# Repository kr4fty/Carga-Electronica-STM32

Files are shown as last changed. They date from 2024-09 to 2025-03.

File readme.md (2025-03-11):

# CARGA ELECTRÓNICA FANTASMA

La carga electrónica fantasma es un dispositivo diseñado para simular una carga eléctrica, utilizado principalmente para pruebas y mediciones. 

Este proyecto está basado en un microcontrolador STM32F103, el cual controla la Vgs del MOSFET para regular la corriente.

**Estado del proyecto:** Funcional, pero aún en proceso de creación.

----------------- **BAJO SU RESPONSABILIDAD** ----------------------

### Video

[Demo](https://github.com/user-attachments/assets/e986f7fb-c2cd-4f63-a5ff-34d32783e475)

## Preparación Previa

Dado que cada transistor MOSFET presenta un voltaje umbral de puerta a fuente (Vgs Threshold) único, independientemente del fabricante o del código de identificación, es imperativo llevar a cabo mediciones específicas para determinar este voltaje umbral, así como la relación entre el ciclo de trabajo (Duty Cycle) y la corriente.

Para ello, se empleará el proyecto [Data Logger](https://github.com/kr4fty/DataLogger_STM32) con el fin de registrar estos parámetros. Posteriormente, los valores obtenidos se integrarán en este proyecto para facilitar el control adecuado de nuestra carga electrónica.

## Que incluye este repositorio?

Actualmente este repositorio cuenta con:
 - Diseño del hardware necesario para el proyecto
 - Codigo fuentes, tanto el de Control como la de adquicision de Datos
 - Archivo necesario para simular la placa BluePill, mediante PICSIMLAB

## Materiales

- **Placa:** BLUE PILL (STM32F103)
- **Encoder con botón**
- **Pantalla LCD:** Nokia 5110
- **Buzzer**
- **Sensor de temperatura:** LM35
- **Cooler Fan**
- **Transistor/s MOSFET:** IRFZ44
- **Sensor de corriente:** ACS712-05B

## Principio de Funcionamiento

El MOSFET opera en la zona de saturación (o zona lineal), lo que permite mantener una corriente constante independientemente de la tensión Vds de entrada. Esta característica es ventajosa para nuestra aplicación, ya que al variar la tensión Vgs podemos ajustar la corriente de salida de manera precisa.

La tensión Vds será controlada mediante el STM32F103 utilizando modulación por ancho de pulso (PWM) y un filtro pasa-bajos para obtener una señal de conversión digital a analógica (DAC) de 12 bits.

Debido a la inestabilidad de la potencia con respecto a la temperatura de los mosfset, el lazo de control sera realizado mediante un PID, el cual debera tener en cuenta el rango de temperaturas no solo para mantener la corriente constante, si no tambien para mantener a salvo al dispositivo.

#### Consideraciones importantes de los transistores Mosfet

- **Tensión de umbral (Vgs threshold):** Es el voltaje mínimo que debe aplicarse entre la puerta y la fuente para que el MOSFET comience a conducir corriente entre el drenador y la fuente.
- **Disipación de potencia:** Operar en la zona de saturación genera una significativa disipación de potencia en el MOSFET. Por lo tanto, es necesario implementar un sistema de disipación forzada para evitar el sobrecalentamiento.

#### Modos de Operacion
* Modo de **Corriente Constante**: Este es el modo predeterminado de operación, en el cual el dispositivo mantiene un nivel de corriente constante, determinado por el operador. Este modo es ideal para evaluar el comportamiento de una fuente o batería al operar bajo una corriente estable.
* Modo de **Potencia Constante**: En este modo, el dispositivo ajusta automáticamente la corriente para mantener la potencia consumida constante en la carga. Este enfoque es útil en situaciones donde es crítico mantener un nivel de potencia específico.
* Modo de **Tiempo**: Este modo permite al operador establecer un intervalo de tiempo durante el cual la carga permanecerá activa. Se pueden utilizar cualquiera de los modos anteriores en conjunto con este, según las necesidades de la aplicación.

## Modo de Funcionamiento

 * Al encender el equipo:
  El sistema muestra una pantalla con los siguientes parámetros:
    * **Tensión mínima (Vmin Limite):** 0.00 V (por defecto).
    * **Corriente de carga:** 1.00 A (por defecto).
    * **Modo de Operación:** "Corriente Constante" (por defecto).

 * Modificación de parámetros:
    * **Selección de parámetros:** Gira el encoder para resaltar el parámetro deseado (se invertirán los colores en el seleccionado).
    * **Edición de parámetros:** Realiza un giro rápido hacia la izquierda para entrar en modo edición. El parámetro comenzará a parpadear.
    * **Ajuste de valores:** Gira el encoder para incrementar o decrementar el valor.
    * **Confirmación:** Espera 2 segundos para salir del modo edición.

* Inicio del proceso:
    * **Inicio:** Haz un click corto en el botón para comenzar el proceso.
    * **Parada:** Un click corto detendrá el proceso.

* Modificación de parámetros estando el proceso en funcionamiento:
    - Puedes editar los parámetros de la misma manera que en el estado inicial de arranque (selección y edición).

* Menú:
    * **Acceso al menú:** Haz un doble click en el botón.

    * **Opciones del menú:**
        * Configurar
            * Backlight.
        * Modo de Trabajo
            * Corriente Cte.
            * Potencia Cte.
            * Resistencia Cte.
            * Tiempo Limite
            * Prueba de carga
            * Reset modo actual
        * Set Vmin Limite
        * Calibración
            * Calibrar
            * Ver parámetros
            * Borrar parámetros
        * Reiniciar MCU
        * Salir del Menú

## Hardware

El diseño del hardware se realizó utilizando KiCad, y se ha optimizado para facilitar la conexión de todos los componentes. A continuación, se detallan los aspectos clave del diseño:

### Consideraciones de Diseño

- **Disipación de Calor:** Asegúrate de que el MOSFET esté montado en un disipador de calor adecuado para evitar el sobrecalentamiento durante su operación.
- **Conexiones Seguras:** Verifica que todas las conexiones sean seguras y que no haya cortocircuitos, especialmente en la zona de alimentación.
- **Alimentación:** Utiliza una fuente de alimentación adecuada que pueda proporcionar la corriente necesaria para la carga que se va a simular.

### Imagen del PCB

Esquema del Hardware
---

Este documento proporciona una visión general del proyecto y su funcionamiento. Asegúrate de seguir las indicaciones de seguridad al trabajar con componentes electrónicos y realizar pruebas.

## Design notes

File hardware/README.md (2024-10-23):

# Hardware

Diseño realizado en KiCAD 8.0.4

## Diagrama electrónico

Diagrama

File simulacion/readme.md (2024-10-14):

# SIMULACIÓN

PICSIMLAB

### PASOS para realizar la simulación

1. Instalar [PICSIMLAB](https://github.com/lcgamboa/picsimlab)
2. Abre el archivo `Carga.pzw` con PICSIMLAB (`File->Load Workspace`); este se ejecutará automáticamente.
3. Si deseas cargar un archivo BIN, asegúrate de seleccionar el entorno **generic_qemu** dentro de `platformio.ini` y luego compilarlo:

**platformio.ini**
``` platformio.ini
[platformio]
;default_envs = nanoatmega328
;default_envs = wroom
;default_envs = generic_dfu
;default_envs = generic_hid_dapboot
;default_envs = generic_hid
;default_envs = generic_serial
;default_envs = generic_stlinkv2
default_envs = generic_qemu         ; <----- DESCOMENTAR!!!

...

[env:generic_qemu] ; Usando qemu, https://lcgamboa.github.io/picsimlab_docs/0.9.2/armgdbDebug.html#x50-490006.3.1
platform = ststm32
board = bluepill_f103c8_128k
board_build.mcu = stm32f103c8t6
;board_build.core = maple
framework = arduino

upload_protocol = custom
...
```

Por ultimo, vamos a importar el BIN generado (`firmware.bin`)

```
File -> Load Bin
```

Y nos dirigimos a la dirección:

```
.pio/build/generic_qemu/firmware.bin
```

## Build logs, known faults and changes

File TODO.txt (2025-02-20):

IMPLEMENTACIÓN DE UN DAC (BluePill no cuenta con DAC)
-----------------------------------------------------
    Generar una salida PWM + filtro pasa bajos. Tener en cuenta la frecuencia 
    del PWM y la frecuencia de corte del filtro para la tasa de bits máxima del
    PWM en nuestra placa BluePill. A su vez la salida este MCU tiene una salida
    lógica de 3.3V, por lo que el filtro deberá tener una ganancia, dependiendo
    de la Vgs Threshold del mosfet
    SOLUCIÓN IMPLEMENTADA:
                    Se utiliza un Filtro Activo tipo Bessel de 2do Orden con una 
                    ganancia de 1.51
            http://sim.okawa-denshi.jp/en/OPseikiLowkeisan.htm

Manejo de un LCD [ HECHO ]
-------------------------
    Se usara un lcd de un Nokia 3310

Control de el mosfet que activa el Cooler Fan, driving
-----------------------------------------------------
    Como la salida lógica del STM32 es 3.3V, tendría que cambiar este IRF540N 
    por un 2N7002, por ejemplo. Revisar cuanto consume el cooler!!!
    SOLUCIÓN IMPLEMENTADA:
            Se implementa un driver simple mediante un transistor NPN
            https://www.laboratoriogluon.com/controlar-mosfets-de-potencia-irfz44n-con-3-3v/

Sensores de Tensión de la Batería
---------------------------------
    Se utiliza un divisor resistivo

    SOLUCIÓN IMPLEMENTADA:
                            Para calcularla see toma el valor de la tensión a 
                            1V y luego para calcular la V se utiliza la 
                            relación:
                                        V = ADC_V_ACTUAL / ADC_1V

Sensor de corriente ASC712
--------------------------
    La tensión de salida (Vout) del ACS712-05B se puede calcular utilizando la
    siguiente fórmula:

        Vout = Vcc/2 + (Sensibilidad x Corriente)

    donde Vcc es la tensión de alimentación del sensor (que es de 5V en este caso),
    Sensibilidad es la sensibilidad del sensor (que es de 0,185 V/A para el ACS712-05B) y 
    Corriente es la corriente que se está midiendo.

    Si asumimos que la tensión de alimentación es de 5V, la fórmula se convierte en:

        Vout = 2,5V + (0,185V/A x Corriente)

    Para una corriente de 5A, la tensión de salida sería:

        Vout = 2,5V + (0,185V/A x 5A)
        Vout = 2,5V + 0,925V
        Vout = 3,425V

    SOLUCIÓN IMPLEMENTADA:
                            Se toma el valor de la corriente a 0A y luego como 
                            referencia, la de 1A. Luego para calcular la I se
                            utiliza la relación:

                            I = (ADC_I_ACTUAL-ADC_0A) / (ADC_1A-ADC_0A)

Sensor de Temperatura LM35
--------------------------
    Rango de salida: de 0 a 1.5V máximo, en la configuración básica (2 a 150ºC)
            NO haría falta un convertidor de niveles 3.3 a 5V
            http://www.ocfreaks.com/interfacing-lm35-sensor-lpc2148/

Interrupciones del PWM cuando se usa tone()
-------------------------------------------
    Al invocar la función tone() de Arduino y mientras se tiene activa otra 
    salida PWM, se observa que se produce una interrupción en la salida de 
    dicho pin.
    
    SOLUCIÓN:
            Se implemento una función tone() personalizada, utilizando el TIM2,
            canal 2, perteneciente al gpio PA1

Interfaz
--------
    Estando apagado(a la espera)
        Mostrar la corriente de Carga deseada
    
    Estando encendido
        * Mostrar de alguna manera (por presión larga del botón, por ejemplo), 
          la corriente de salida seleccionada
        * Posibilidad de modificar dicha corriente de salida

        SOLUCIÓN IMPLEMENTADA:
                                Al girar el Encoder, se modificara
                                automáticamente el nuevo Setpoint. No hace
                                falta presionar el botón. Por ahora :|

EEPROM
------
Guardar el ultimo valor de corriente utilizado. De este modo en la próxima 
encendida ya podemos recuperarlo fácilmente.

    Se utilizará la implementación de Arduino, EEPROM.h

Salida PWM múltiple para el control de dos mosfet
-------------------------------------------------
    La idea es poder extender el rango de corriente de salida, pero por la 
    utilización de dos MOSFET de modo que la corriente quede divida y por lo 
    tanto cada uno calentara menos

    SOLUCIÓN IMPLEMENTADA:
                            Se utiliza dutycyle fijo en el segundo MOSFET, a la
                            mitad del setpoint.
                            ampereSetpoint = dutyCycleToAmpere(dutyCycle);
                        Output2 = ampereToDutycycle(ampereSetpoint/2, MOSFET2);

Ver estado de la Tensión de Entrada
-----------------------------------
    Esto es para no arrancar el PID si todavía no se conecto la BATERÍA/FUENTE
    Si el PID se sigue calculando en ausencia de Tensión, cuando conectamos la
    batería, la carga consume el máximo ya que estuvo intentando subirla, 
    máximo PID.

Pulsación larga para reiniciar parámetros
-----------------------------------------
    Una pulsación larga me reinicia los contadores de Tiempo, Wh y mAh

Alarmas por caída en la fuente a testear
----------------------------------------
    Indicar si la fuente cae demasiado, por debajo de un 15% por ejemplo, en su
    tensión de salida. Esto para indicar la calidad y si cumple con los 
    parámetros de salida indicadas.

dutyCycle a Amperes
-------------------
    Cuando se setea el nuevo setpoint por medio del encoder, la conversion 
    debería ser en función del ACS712?????

    selecciono corriente -> convierto a ADC -> convierto a dutyCycle

Agregar Modos de funcionamiento
-------------------------------
    Por ejemplo:
                Corriente constante por un determinado Tiempo
                Watts constantes
                Medición de mAh de una batería
                Reacción frente a pulsos de corriente, para ver si cae la Vin

    En Modo Potencia constate, que debería hacer?:
        * Configurar el *encoder* para tener nuevo rango de limites
          Si considero que voy a medir un máximo de 100W y con una resolución
          de 0.1W, por ejemplo, entonces mis limites serian de 0 a 1000.
        * Modificar la variables de control dependiendo del tipo de MODO
          seleccionado.
          Ahora el Input seria la tensión y corriente (potencia) leídas en cada
          ciclo. A su vez el Setpoint sera la Potencia deseada. En tanto el 
          Output seguirá siendo dutyCycle ya que es el único parámetro que se 
          puede controlar para controlar la corriente.
          Tener en cuenta que en este caso variaran tanto la tensión como la
          la corriente al mismo tiempo(en el mejor de los casos solo variara 
          uno, dependiendo del tipo de fuente). Por lo que el Setpoint deberá 
          ajustarse continuamente ya que solo podemos controla la corriente.
        * Modo Inteligente (Prueba de carga)
          Con este modo se intentaría comprobar el valor de corriente máxima
          entregada por una fuente.
          En dicho modo se debería ir subiendo, desde 0 por ejemplo, la
          corriente hasta que veamos que la fuente cae por debajo de un 10/15% 
          de su valor nominal

Formas en que se muestra la Corriente [HECHO]
-------------------------------------
    Para corriente menor a 1A, 1000mA, se debería mostrar otra escala

        por ejemplo: en lugar de mostrar 0.15A se debería mostrar 150mA

Notificación cuando se conecta/desconecta la fuente/batería estando Menu activo
-------------------------------------------------------------------------------
    Resulta molesto la notificación de "No battery" cuando se ingresa a la
    configuración.
    En caso de ingresar al Menu, debería inhabilitarse las notificaciones hasta
    que se sale de dicho Menu.

        Solo voy a mostrar la notificación de Batería desconectada, cuando no
        este dentro del Menu

Limite inferior, V min, de descarga
-----------------------------------
    El limite inferior de descarga es para no dañar las baterías, ya que si
    bajan por debajo de 2.7V, por ejemplo, podrían dañarse.
    También si se quiere poner otro limite seguro de caída tensión, en fuentes
    o baterías.

        Al iniciar, girando el Encoder seleccionamos para setear la V min o la
        Corriente de Carga. Para configurar el parámetro deseado hacemos un
        click, corto, movemos el encoder para setear el valor y por ultimo
        hacemos otro click corto para volver a la selección de configuración.
        Una vez seteado los dos parámetros o solo el deseado, hacemos un click
        Largo para continuar y arrancar el proceso.

        En caso de NO querer modificar ninguno de los parámetros en el arranque,
        solo basta con hacer un Click Largo y ya podemos iniciar el proceso 
        normalmente.
        
        Si quisiéramos modificar la V min cuando el proceso ya esta en 
        funcionamiento, solo debemos entrar al Menu, con Doble click, y ahi
        vamos a  "Configurar" y seleccionamos "V mínimo" para modificarlo.

        Al iniciar, ya configurado los parámetros iniciales, o no, y estando el
        proceso apagado, se mostrara los limites configurados de Tensión y
        Corriente en colores invertidos.

Interfaz simplificada [NO IMPLEMENTADA]
---------------------
    La idea es hacerla lo mas simple posible, que para activar la Carga, la 
    idea es que la misma tenga la menor cantidad de pasos. Por ejemplo:

        Arranca y muestra la Corriente en negrita, signo de que ese parámetro
        se puede modificar. Caso contrario, girando hacia la derecha, me cambia
        hacia otro parámetro. Por ejemplo la secuencia:

            ...->Corriente->mAh->Wh->Tiempo->Tensión de corte->Corriente->.....
        
        Si giro hacia la izquierda, estando resaltado el parámetro que quisiera
        modificar, comienza a parpadear (cambiando Negro sobre blanco a Blanco 
        sobre Negro), se habilita para modificarlo.
        Luego si el parámetro esta en el valor deseado, solo con hacer un click
        corto ya quedaría seteado.

        Finalmente para arrancar el proceso hacemos un Click, suponiendo que 
        los parámetros ya están en los valores deseados.

        En caso de Iniciar y querer usar la configuración por default, solo 
        bastaría con hacer un Click para que se inicie.

        En caso de ya estar en funcionamiento el proceso y si se quisiera 
        modificar algún parámetro, solo bastaría con hacer un Doble Click para 
        ingresar al Menu y desde ahi modificar lo deseado.

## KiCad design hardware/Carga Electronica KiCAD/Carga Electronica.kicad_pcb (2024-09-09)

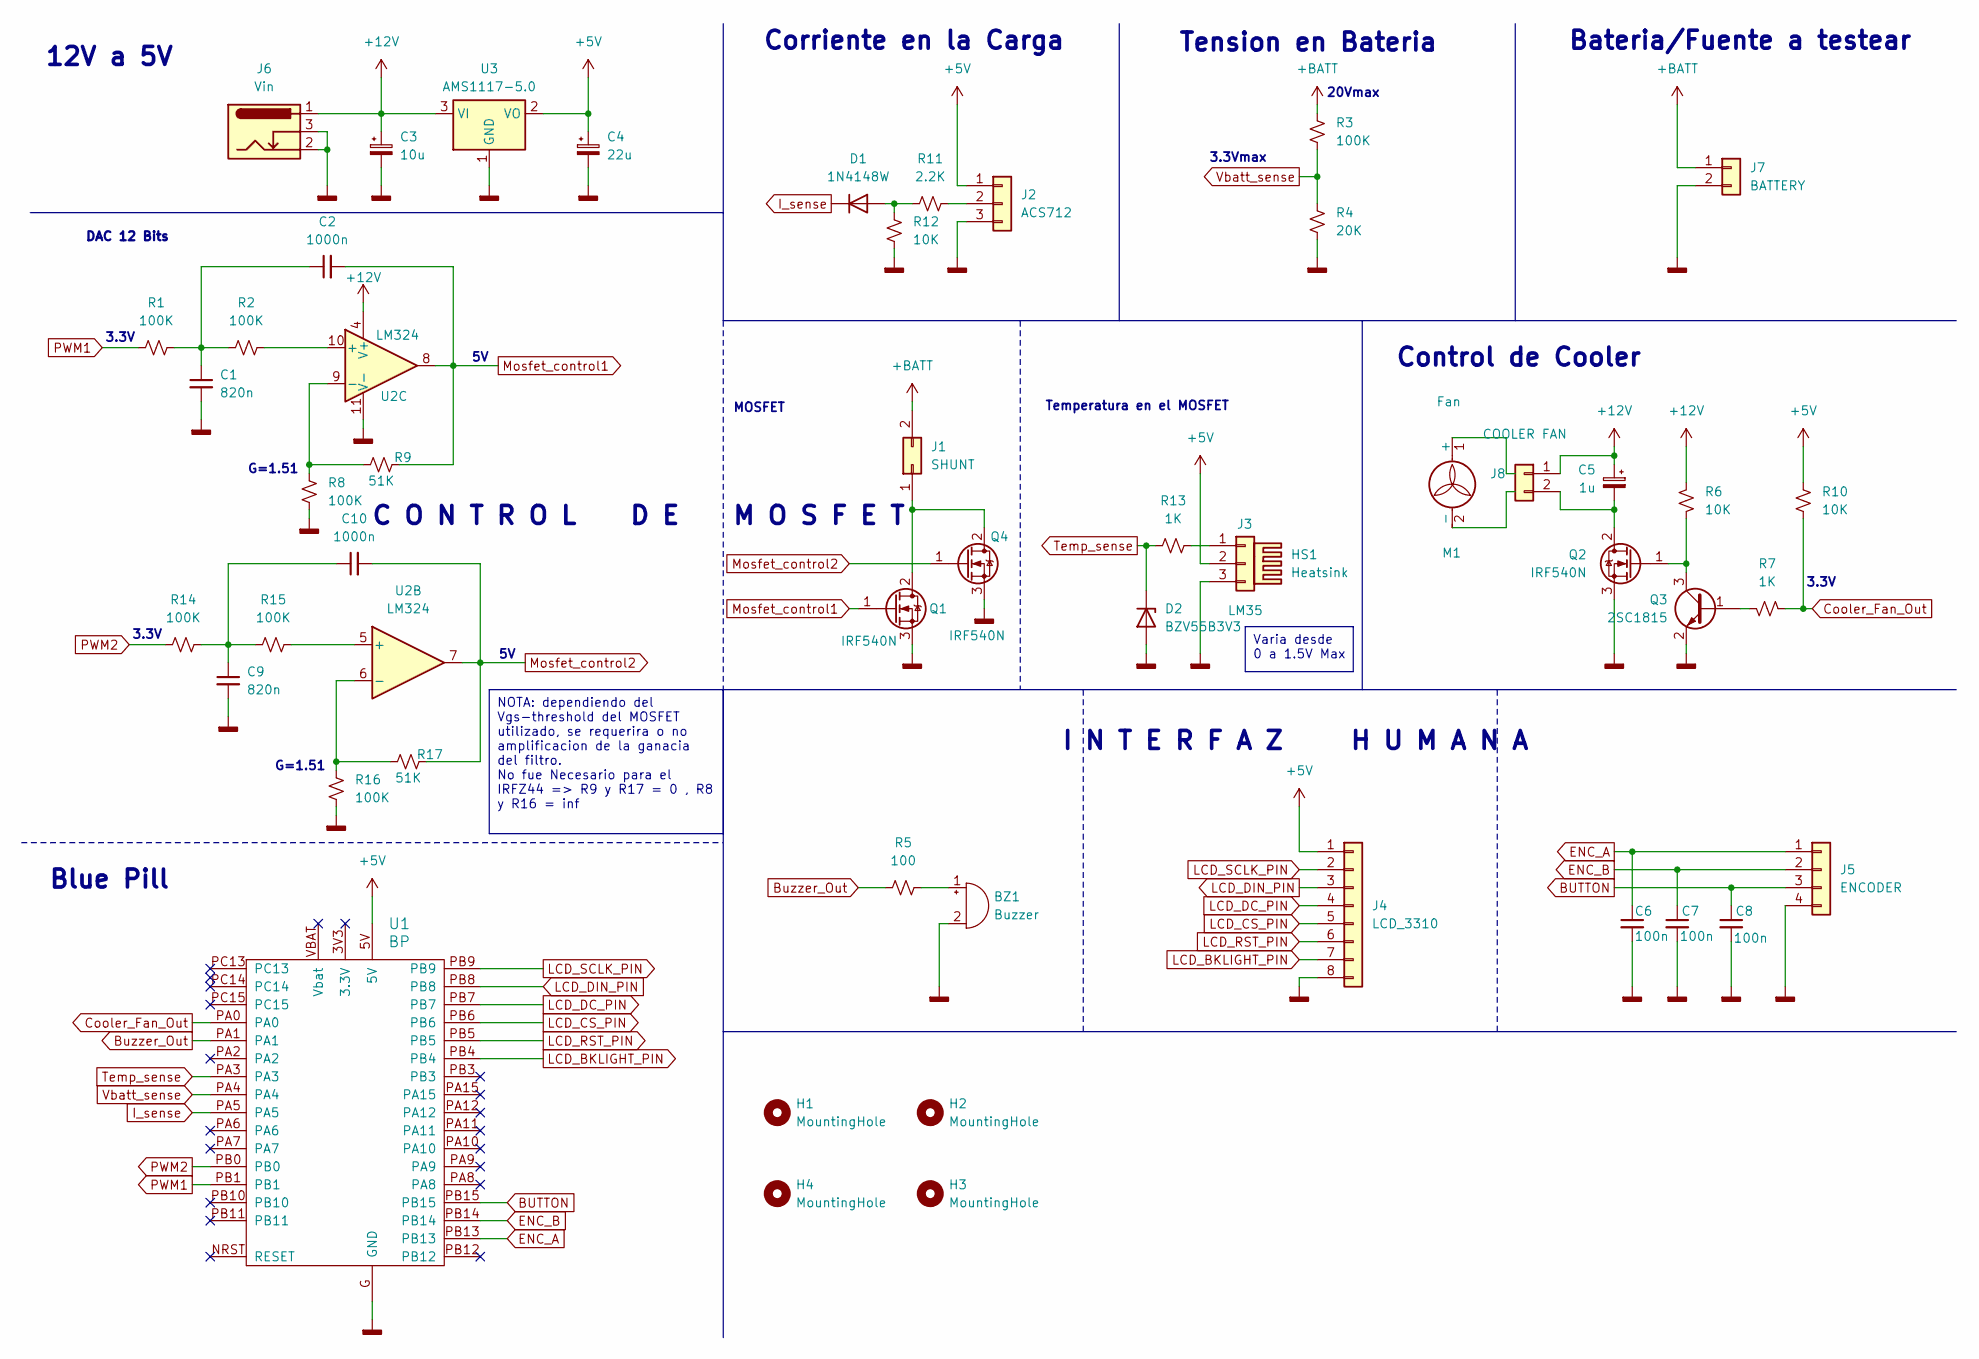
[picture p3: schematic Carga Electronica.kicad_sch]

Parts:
BZ1: Buzzer; Buzzer_TDK_PS1240P02BT_D12.2mm_H6.5mm
C1, C9: 820n; C_0805_2012Metric_Pad1.18x1.45mm_HandSolder
C2, C10: 1000n; C_0805_2012Metric_Pad1.18x1.45mm_HandSolder
C3: 10u; CP_Elec_6.3x5.2
C4: 22u; CP_Elec_6.3x5.2
C5: 1u; CP_Elec_6.3x5.2
C6, C7, C8: 100n; C_0805_2012Metric_Pad1.18x1.45mm_HandSolder
D1: 1N4148W; D_SOD-123
D2: BZV55B3V3; D_MiniMELF
H1, H2, H3, H4: MountingHole; MountingHole_2.5mm
HS1: Heatsink
J1: SHUNT; Molex_KK-396_5273-02A_1x02_P3.96mm_Vertical
J2: ACS712; Molex_KK-254_AE-6410-03A_1x03_P2.54mm_Vertical
J3: LM35; Molex_KK-254_AE-6410-03A_1x03_P2.54mm_Vertical
J4: LCD_3310; Molex_KK-254_AE-6410-08A_1x08_P2.54mm_Vertical
J5: ENCODER; Molex_KK-254_AE-6410-04A_1x04_P2.54mm_Vertical
J6: Vin; BarrelJack_Horizontal
J7: BATTERY; Molex_KK-396_5273-02A_1x02_P3.96mm_Vertical
J8: COOLER FAN; Molex_KK-396_5273-02A_1x02_P3.96mm_Vertical
M1: Fan; Molex_KK-254_AE-6410-02A_1x02_P2.54mm_Vertical
Q1, Q4: IRF540N; Molex_KK-396_5273-03A_1x03_P3.96mm_Vertical
Q2: IRF540N; TO-220-3_Vertical
Q3: 2SC1815; SOT-23
R1, R2, R8, R14, R15: 100K; R_0805_2012Metric_Pad1.20x1.40mm_HandSolder
R3, R16: 100K; R_1206_3216Metric_Pad1.30x1.75mm_HandSolder
R4: 20K; R_1206_3216Metric_Pad1.30x1.75mm_HandSolder
R5: 100; R_1206_3216Metric_Pad1.30x1.75mm_HandSolder
R6, R10: 10K; R_1206_3216Metric_Pad1.30x1.75mm_HandSolder
R7: 1K; R_1206_3216Metric_Pad1.30x1.75mm_HandSolder
R9, R17: 51K; R_0805_2012Metric_Pad1.20x1.40mm_HandSolder
R11: 2.2K; R_0805_2012Metric_Pad1.20x1.40mm_HandSolder
R12: 10K; R_0805_2012Metric_Pad1.20x1.40mm_HandSolder
R13: 1K; R_0805_2012Metric_Pad1.20x1.40mm_HandSolder
U1: BP; blue_pill_no_flashing_port
U2: LM324; SOIC-14_3.9x8.7mm_P1.27mm
U3: AMS1117-5.0; SOT-223-3_TabPin2

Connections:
+5V: C4.1, J2.1, J3.2, J4.1, R10.1, U1.5V, U3.2 (VO)
+12V: C3.1, C5.1, J6.1, J8.1, R6.1, U2.4 (V+), U3.3 (VI)
+BATT: J1.2, J7.1, R3.1
BUTTON: C8.1, J5.3, U1.PB15
Buzzer_Out: R5.1, U1.PA1
Cooler_Fan_Out: R7.2, R10.2, U1.PA0
ENC_A: C6.1, J5.1, U1.PB13
ENC_B: C7.1, J5.2, U1.PB14
GNDD: BZ1.2 (-), C1.2, C3.2, C4.2, C6.2, C7.2, C8.2, C9.2, D2.2 (A), J2.3, J3.3, J4.8, J5.4, J6.2, J6.3, J7.2, Q1.3 (S), Q2.3 (S), Q3.2 (E), Q4.3 (S), R4.2, R8.2, R12.2, R16.2, U1.G (GND), U2.11 (V-), U3.1 (GND)
I_sense: D1.1 (K), U1.PA5
LCD_BKLIGHT_PIN: J4.7, U1.PB4
LCD_CS_PIN: J4.5, U1.PB6
LCD_DC_PIN: J4.4, U1.PB7
LCD_DIN_PIN: J4.3, U1.PB8
LCD_RST_PIN: J4.6, U1.PB5
LCD_SCLK_PIN: J4.2, U1.PB9
Mosfet_control1: C2.2, Q1.1 (G), R9.2, U2.8
Mosfet_control2: C10.2, Q4.1 (G), R17.2, U2.7
unnamed: BZ1.1 (+), R5.2
unnamed: C1.1, C2.1, R1.2, R2.1
unnamed: C9.1, C10.1, R14.2, R15.1
unnamed: D1.2 (A), R11.1, R12.1
unnamed: J1.1, Q1.2 (D), Q4.2 (D)
unnamed: J2.2, R11.2
unnamed: J3.1, R13.2
unnamed: C5.2, J8.2, Q2.2 (D)
unnamed: Q2.1 (G), Q3.3 (C), R6.2
unnamed: Q3.1 (B), R7.1
unnamed: R15.2, U2.5 (+)
unnamed: R16.1, R17.1, U2.6 (-)
unnamed: R2.2, U2.10 (+)
unnamed: R8.1, R9.1, U2.9 (-)
PWM1: R1.1, U1.PB1
PWM2: R14.1, U1.PB0
Temp_sense: D2.1 (K), R13.1, U1.PA3
Vbatt_sense: R3.2, R4.1, U1.PA4

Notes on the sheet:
NOTA: dependiendo del Vgs-threshold del MOSFET utilizado, se requerira o no amplificacion de la ganacia del filtro. No fue Necesario para el IRFZ44 => R9 y R17 = 0 , R8 y R16 = inf
Varia desde 0 a 1.5V Max
C O N T R O L D E M O S F E T
Corriente en la Carga
G=1.51
3.3V
MOSFET
Control de Cooler
DAC 12 Bits
Temperatura en el MOSFET
3.3Vmax
Tension en Bateria
Blue Pill
I N T E R F A Z H U M A N A
12V a 5V
20Vmax
Bateria/Fuente a testear

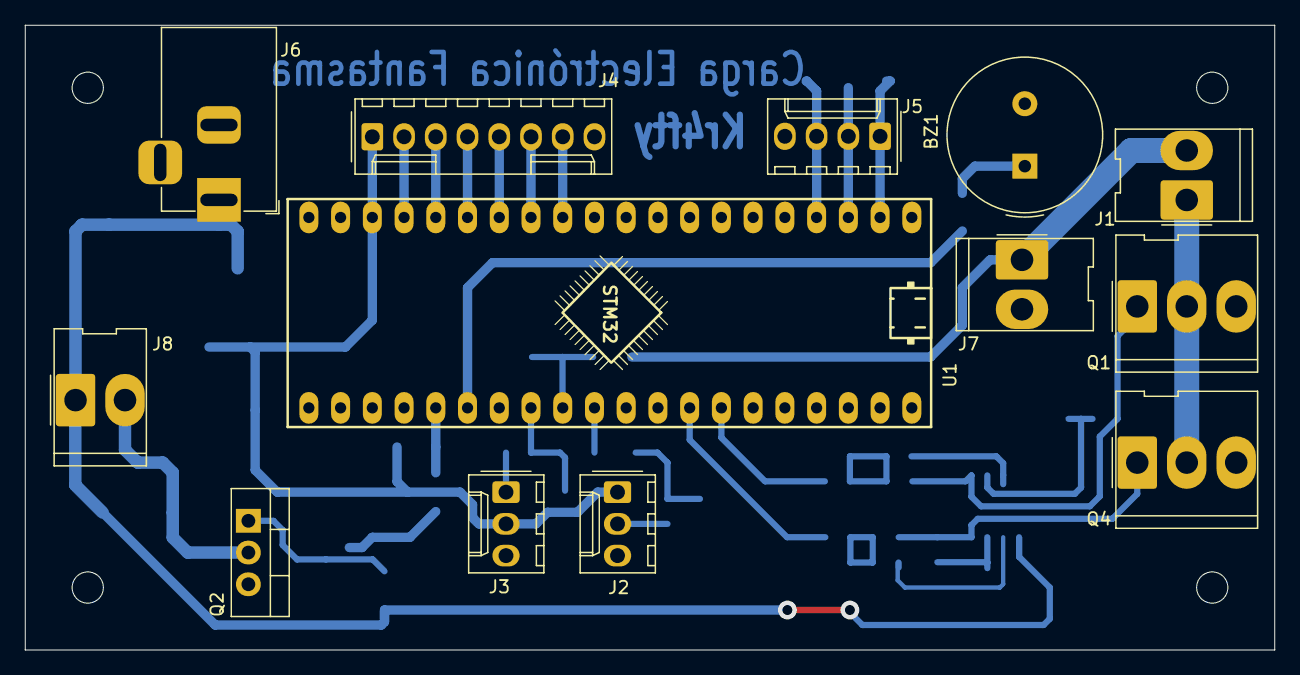
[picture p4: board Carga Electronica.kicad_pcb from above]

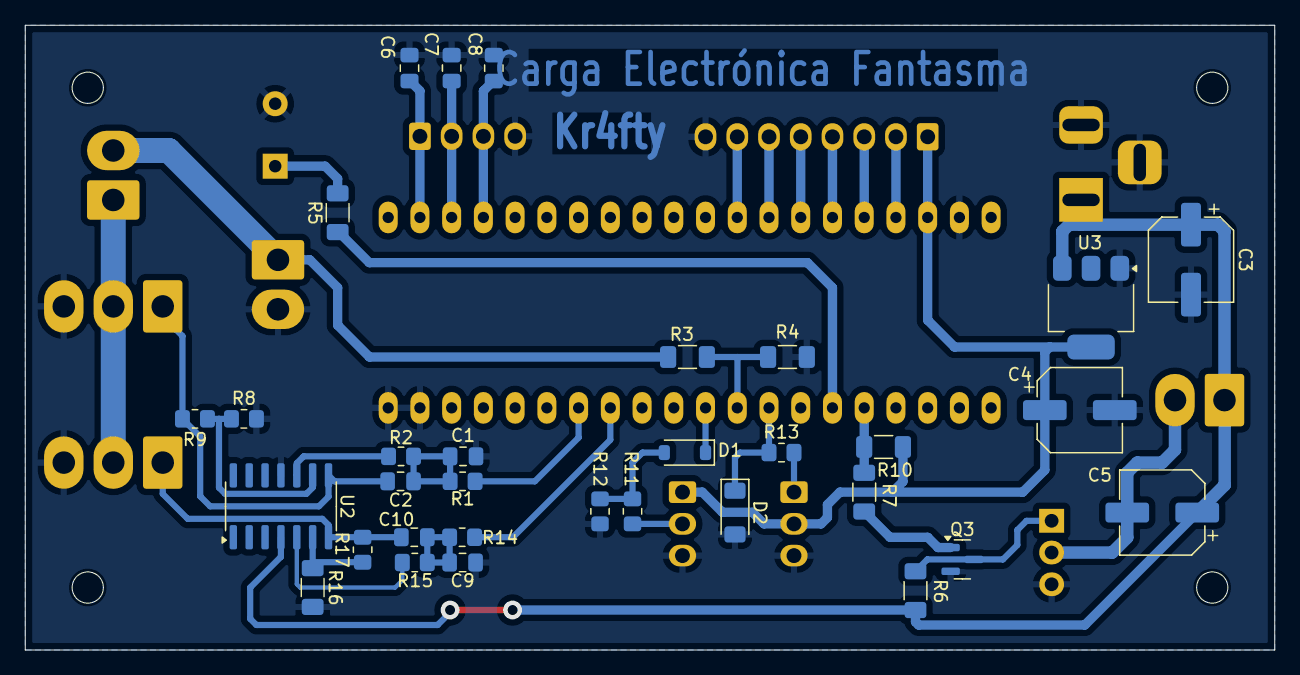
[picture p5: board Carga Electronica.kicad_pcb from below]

Board: 2 copper layers, 100.0 x 50.0 mm, 49 parts (32 on the bottom side), 36 nets.

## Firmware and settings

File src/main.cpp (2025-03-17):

#include <Arduino.h>
#include <PID_v1.h>
#include "config.h"
#include "encoder.h"
#include "display.h"
#include "pwm.h"
#include "sound.h"
#include "tclock.h"
#include "constantes.h"
#include "coolerfan.h"
#include "conversion.h"
#include "notifications.h"
#include "myMenu.h"
#include "calibrate.h"
#include "modes.h"
#include "control.h"

long encoderValue = 0;// Valor leído desde el encoder
float ampereSetpoint;// Contiene el valor del Setpoint expresado en Amperes
float powerSetpoint;// Contiene el valor de Setpoint expresado en Watts
float resistanceSetpoint; // Contiene el valor del Setpoint expresado en Ohmios
float vLimit=0;     // Valor de la tensión mínima de corte
double vBattRawOld; // Valor de lectura anterior del pin ADC que mide V
double iBattRawOld; // Valor de lectura anterior del pin ADC que mide I
double iAdcOffset;  // Lectura del ADC medida en vació (0 A)
double AdcRaw_1A;   // Lectura del ADC midiendo 1A
double Adc1aDiff;   // Contiene la diferencia en valores de ADC, entre 1A y 0A
float iIn, vIn, vInOld, wIn, totalmAh, totalWh; // Valores actuales de la V, I y Wh
uint8_t key; // 0: no click, 1: corta, 2: larga, 3: doble pulsación

double Setpoint, Input, Output; // Parámetro PID
//Specify the links and initial tuning parameters
PID myPID(&Input, &Output, &Setpoint, KP_AGG, KI_AGG, KD_AGG, DIRECT);
unsigned long windowStartTime;

#ifdef DEBUG
unsigned long nextTime, startTime, actualTime;
#define WINDOW_CAPTURE  40
#define WINDOW_10SEG 10000
#endif

void setup() {
    #ifdef DEBUG
    Serial.begin(115200);
    delay(5000);
    Serial.println("Iniciando");
    #endif
    pinMode(LED, OUTPUT);
    digitalWrite(LED, HIGH);
    
    lcd_init();
    encoder_init();
    pwm_init();
    coolerFan_init();
    tone_init();

    myPID.SetOutputLimits(ADC_VGS_THRESHOLE, 4095);
    myPID.SetSampleTime(PID_WINDOW_SIZE);  //sets the period, in Millisecond
    myPID.SetMode(AUTOMATIC); // Encendemos el PID

    // Lectura inicial de los sensores
    vBattRawOld = analogRead(VBATT_SENSE_PIN);
    iBattRawOld = analogRead(IBATT_SENSE_PIN);

    // Entrando a modo Calibración. Medimos una corriente de 1A para luego aplicar relación
    if(isButtonDown())
    {
        calibration_calibrate();
        if(!iAdcOffset || !AdcRaw_1A){
            calibration_resetParameters();
        }
    }
    else{
        // Recupero los parámetros de calibración de la Corriente desde la EEPROM
        calibration_readParameters();
    }

    vLimit = V_0V;              // 0 Volt
    controlMode; // Por default esta en C_CONST_MODE
    
    ampereSetpoint = C_1A;      // 1 Ampere
    powerSetpoint = P_1W;       // 1 Watt
    resistanceSetpoint = R_10R; // 10 Ohm

    //lcd_printBaseFrame(controlMode);
    lcd_printSelectBaseFrame();

    windowStartTime = millis();

    encoder_setBasicParameters(0, 299, true, 1, 2); // Configuro para selección de parámetro a modificar

    lcd_printSelectedParam(1, controlMode, COLOR_WB); // resalto
            
    encoderValue = encoder.readEncoder();

    Setpoint = 0;

    // Inicio Proceso de control
    tone(BUZZER_PIN, 2600, 250);
}

bool isPowerOn = false; // TRUE: en funcionamiento
long encoderValueChanged; // True: el valor del encoder cambio
int8_t encoderDirection;
double vRaw; // Valor crudo de la tensión de entrada, sin aplicar filtro, para detectar mas rápidamente la desconexión de la batería
double vBattRaw, iBattRaw; // Valores Leidos en los ADC
bool batteryConnected=true;  // True si se detecto tensión de sensado de batería
bool wasVUpdated=true, wasIUpdated=true, wasXhUpdated=true, wasTempUpdated=true; //True: Si los valores cambiaron, para re imprimir
bool wasCtrlModeUpdated=true;
uint16_t mosfetTempRaw, oldMosfetTempRaw;
float mosfetTemp; 
long timeToUpdateDisplay=millis()+DISPLAY_UPDATE_WINDOW;
uint8_t notificationPriority; // Contiene la prioridad de notificaciones
uint16_t time_mseg; // Tiempo en mili segundos
bool forceRePrint; // Para volver a imprimir toda la pantalla
bool isItOverheating=false;
bool isPrintTime=true;
bool isTheSetpointUpdated; // Para tener prioridad al mostrar nuevo setpoint
bool printTinySetpoint=true;
unsigned long timeToPrintNewSetpoint, windowNewSetpoint=2000;
double Output2; // Contiene el duty del segundo MOSFET. Varia con el setpoint
uint8_t oldControlMode; // Contiene el estado anterior del modo de control
long oldEncoderValue; // Para restaurar el valor del encoder al salir del menú
unsigned long timeLoadTestStart;
float vInNominal, vMaxForImax, iMax;
uint8_t paramNumber=1, oldParamNumber=0; // Parámetro seleccionado actual y anterior
long eventStartTime, eventEndTime; // Registran el tiempo de inicio y final del evento
long pulseCount; // Contador de ticks en cada evento (giro del encoder)
bool newValue; // True: si hubo un cambio, admitido, en el encoder
bool modifyParameter; // True: se entro en modo edición del parámetro seleccionado
bool actualColor; // Color actual del parámetro
bool firstTime=true; // True: para ejecutar acciones solo en el arranque
uint8_t colorCount; // Contador para indicar el cambio del color, modo edición

void loop() {
    /***************************************************************************/
    /*                    MEDICIÓN DE TENSIÓN Y CORRIENTE                      */
    /***************************************************************************/
    vRaw = analogRead(VBATT_SENSE_PIN);
    // Filtro de Wiener, Adaptativo
    vBattRaw = vBattRawOld + MU * (vRaw - vBattRawOld);  
    // Calculo de vIn
    vIn = 0.01935*vBattRaw + 0.25; // Función obtenida por regresión lineal

    if(vBattRaw != vBattRawOld){// si cambio V entonces actualizo valor en el LCD
        wasVUpdated = true;
        vBattRawOld = vBattRaw;
    }
    
    iBattRaw = (double)analogRead(IBATT_SENSE_PIN);
    // Filtro de Wiener, Adaptativo
    iBattRaw = iBattRawOld + MU * (iBattRaw - iBattRawOld);
    // Calculo iIn
    iIn = (iBattRaw - iAdcOffset) / Adc1aDiff;

    if(iBattRaw != iBattRawOld){ // si cambio I entonces actualizo valor en el LCD
        if(isPowerOn){
            wasIUpdated = true;
        }
        else{
            iAdcOffset = iBattRaw; // Corriente medida, valores de ADC, a 0A

            // Guardo la tensión nominal en vació
            vInNominal = vIn;
        }
        iBattRawOld = iBattRaw;
    }

    // Calculo wIn
    wIn = vIn * iIn;

    // Si vario la Vin entonces recalculo el setpoint para el modo P_CONST_MODE
    if(controlMode==P_CONST_MODE || controlMode==R_CONST_MODE){
        if(vIn != vInOld && isPowerOn){
            // Actualizo valores
            switch (controlMode)
            {
                case P_CONST_MODE:
                    ampereSetpoint =  powerSetpoint/vIn; // Cálculo de la corriente necesaria
                    break;
                case R_CONST_MODE:
                    ampereSetpoint = vIn/resistanceSetpoint; // Cálculo de la corriente necesaria
                break;
                default:
                    break;
            }

            Output2 = ampereToDutycycle(ampereSetpoint*.5, MOSFET2);
            
            Setpoint = ampereToAdc(ampereSetpoint);
            vInOld = vIn;
        }
    }
    // FIN Mediciones

    /***************************************************************************/
    /*                 ¿SE CONECTO LA FUENTE A LA ENTRADA?                     */
    /***************************************************************************/
    // Batería/Fuente conectada y funcionando? Detección persistente
    if(vRaw > VBATT_MIN){
        // Batería conectada
        if(!batteryConnected){
            // Solo se muestra si no se esta el Menu de configuración activo
            if(!showMenu && isPowerOn){
                // Solo mostramos una vez el mensaje
                notificationPriority = 3;
                time_mseg = 500;
                notification_add("BATT CONNECTED", notificationPriority, time_mseg, COLOR_BW);

                batteryConnected = true;
            }
        }
    }
    else{ // NO SE DETECTO TENSIÓN DE ENTRADA!!!
        if(batteryConnected){
            // Solo se muestra si no se esta el Menu de configuración activo
            if(!showMenu && isPowerOn){
                // Se muestra solo una vez y queda fijo hasta que no se cambie el estado
                notificationPriority = 3;
                notification_add("  NO BATTERY  ", notificationPriority, NO_TIME_LIMIT, COLOR_WB);

                // Emito un Sonido de alerta
                tone(BUZZER_PIN, 2000, 50);
                delay(50);
                tone(BUZZER_PIN, 2000, 50);
                delay(50);
                tone(BUZZER_PIN, 2000, 50);

                batteryConnected = false;
            }
            if(isPowerOn){
                control_stopOutputsAndReset();
                //myPID.SetMode(MANUAL);  // Apagamos el PID
            }
        }
    }
    // FIN DETECCIÓN DE TENSIÓN DE ENTRADA

    /******************************* Encoder *********************************/
    encoderValueChanged = encoder.encoderChanged();
    encoderDirection = encoder.getDirection();
    
    if(encoderValueChanged){        
        if(showMenu || modifyParameter){
            encoderValue = encoder.readEncoder();
            
            eventEndTime = millis();
            newValue = true;
        }
        else{
            if(!eventStartTime){
                eventStartTime = millis();
                pulseCount = 0;
            }
            
            pulseCount += encoderDirection;
            eventEndTime = millis();
        }
    }
    if(eventStartTime && !modifyParameter && (millis()-eventEndTime)>40){
        // Estando apagado, se produjo un evento y ya termino
        eventStartTime = 0;
        newValue = true; // Evento finalizado, hay nuevo valor
    }
    if(eventStartTime && modifyParameter && (millis()-eventEndTime)>2000){
        // Se termino el tiempo de espera para la edición del parámetro
        eventStartTime = 0;
        modifyParameter = false; // Ya no estoy en modo edición

        forceRePrint = true; // Fuerzo re imprimir la pantalla

        // Emito un Sonido de alerta
        tone(BUZZER_PIN, 7000, 20);
        delay(75);
        tone(BUZZER_PIN, 7000, 80);

        // Recupero configuración previa del contador del encoder
        if(firstTime){
            encoder_setBasicParameters(0, 299, true, paramNumber, 2);
        }
        else{
            encoder_setBasicParameters(0, 199, true, 1, 2);
        }
    }
    //

    /********************* Selección de Parámetro a modificar ****************/
    if(newValue && !showMenu && !modifyParameter){
        newValue = false;
        // Modificación del parámetro seleccionado
        if(abs(pulseCount)>2){ // Entrando a modo EDICIÓN
            if(encoderDirection<0){
                // Emito un Sonido de alerta
                tone(BUZZER_PIN, 2500, 50);
                tone(BUZZER_PIN, 0, 50);
                tone(BUZZER_PIN, 2500, 50);

                modifyParameter = true; // Modo edición activado

                // Re configurar los parámetros del encoder de acuerdo al modo actual de funcionamiento
                switch (paramNumber)
                {
                    case 0: // Modificación de Vlimit
                        encoder_setBasicParameters(0, 2000, false, vLimit*100, 150);
                        break;
                    
                    case 1: // Modificación de C, W o R
                        switch (controlMode){
                            case C_CONST_MODE:
                                encoder_setBasicParameters(0, 1000, false, ampereSetpoint*100, 100);
                                break;
                            case P_CONST_MODE:
                                encoder_setBasicParameters(0, 1000, false, powerSetpoint*10, 100);
                                break;
                            case R_CONST_MODE:
                                encoder_setBasicParameters(0, 1000, false, resistanceSetpoint*10, 100);
                                break;
                            default:
                                break;
                        }
                        break;
                    case 2: // Modo de operación
                        encoder_setBasicParameters(1, 3, true, 0, 0);
                        wasCtrlModeUpdated = true;
                        break;
                    case 3:
                        break;
                    case 4:
                        break;
                    default:
                        break;
                }
                // Como contiene un valor viejo entonces los actualizo
                encoderValue = encoder.readEncoder(); 

                // limpio 
                lcd_printSelectedParam(paramNumber, controlMode); // limpio

                eventStartTime = millis();
                eventEndTime = millis();
            }
            // 
            if(modifyParameter){
                if(isPowerOn){
                    // Si esta encendido el proceso entonces fuerzo a mostrar 
                    // la ventana del setpoint grande la primera vez
                    newValue = true;
                }
            }
        }
        else{ // Entrando en modo SELECCIÓN
            oldParamNumber = paramNumber;
            if(firstTime){
                paramNumber = encoder.readEncoder()%3;
            }
            else{
                paramNumber = encoder.readEncoder()%2;
            }

            lcd_printSelectedParam(oldParamNumber, controlMode); // limpio selección anterior
            lcd_printSelectedParam(paramNumber, controlMode, COLOR_WB); // resalto el actual

            tone(BUZZER_PIN, 600, 10);
        }
    }
    //

    /******************************** Menú ***********************************/
    if(showMenu && encoderValueChanged){
        // Resalto el nuevo Item seleccionado mediante el encoder
        menu.highlightMenuItem(encoderValue);
    }
    //

    /*************************************************************************/
    /*                      MODIFICACIÓN DE PARÁMETROS                       */
    /*************************************************************************/
    if(!isLoadTestRunning){ // No se selecciono la Prueba de Carga
        if(newValue){
            newValue = false;
            if (!showMenu){
                switch (paramNumber)
                {
                    case 0: // Limite de Tensión
                        vLimit = encoderValue/100.0;

                        if(isPowerOn){
                            lcd_printNewSetpoint(vLimit, V_LIMIT);
                            isTheSetpointUpdated = true;
                        }
                        else{
                            printTinySetpoint = true;
                        }
                        break;
                    case 1: // Limite principal 
                        // Calculo el Setpoint necesario en valores de Ampere normalizados
                        ampereSetpoint = modes_handleEncoderChange(vIn, encoderValue, controlMode);
                        
                        // Se actualizo el Setpoint, por lo que se deberá actualizar la pantalla
                        if(isPowerOn){ // Si esta encendido se mostrara en una ventana temporal
                            switch (controlMode){
                                case C_CONST_MODE:
                                    lcd_printNewSetpoint(ampereSetpoint, controlMode);
                                    break;
                                case P_CONST_MODE:
                                    lcd_printNewSetpoint(powerSetpoint, controlMode);
                                    break;
                                case R_CONST_MODE:
                                    lcd_printNewSetpoint(resistanceSetpoint, controlMode);
                                    break;
                                default:
                                    break;
                            }
                            
                            isTheSetpointUpdated = true;
                        }
                        else{ // Si esta APAGADO se mostrara en lugar de la corriente medida
                            printTinySetpoint = true;
                        }

                        Output2 = ampereToDutycycle(ampereSetpoint*.5, MOSFET2);
                        if(isPowerOn){
                            // Calculo el Setpoint necesario en valores que interpreta el PID
                            Setpoint = ampereToAdc(ampereSetpoint);
                        }
                        break;
                    case 2: // Modo de Operación
                        controlMode = encoderValue;
                        wasCtrlModeUpdated = true;
                        break;
                    case 3:
                        break;
                    case 4:
                        break;
                    default:
                        break;
                }
                
                //tone(BUZZER_PIN, 600, 10);

                timeToPrintNewSetpoint = millis() + windowNewSetpoint;
            }
        }

        // Tiempo de muestra de la Ventana temporal que imprime el nuevo SETPOINT
        if(isTheSetpointUpdated && (millis()>timeToPrintNewSetpoint)){
                isTheSetpointUpdated = false;
                // si estando encendido se desconecta y luego modifico el setpoint, no se reimprime la notificación
                control_forceReprintDisplay();

                tone(BUZZER_PIN, 7000, 20);
                delay(75);
                tone(BUZZER_PIN, 7000, 80);
        }
        // FIN CONFIGURACIÓN DE CORRIENTE DE CARGA
    }
    /***************************************************************************/
    /*                              PRUEBA DE CARGA                            */
    /***************************************************************************/
    else{
        // Cada determinado tiempo incremento ampereSetpoint
        if(isPowerOn && isLoadTestRunning){
            if(millis() > (timeLoadTestStart+250)){
                ampereSetpoint += 0.01;
                Output2 = ampereToDutycycle(ampereSetpoint*.5, MOSFET2);                
                Setpoint = ampereToAdc(ampereSetpoint);
                
                timeLoadTestStart = millis();
            }
        }

        // Verifico que la tensión no haya caído por debajo de 85% de la nominal
        if(vIn < (0.85*vInNominal)){// Cayo por debajo, apago el control
            // Apago las salidas PWM
            control_powerOff();
            // Presento informe de salida
            lcd_printShowLoadTestResults(vMaxForImax, iMax);
            // Espero por un click en el botón
            while(!isButtonClicked());
            // Re imprimo todo como si se encendiese por primera vez
            isPowerOn = false;
            control_forceReprintDisplay();
            // Limpio contadores y reloj
            control_resetAllForNewMode();
            // Deshabilito la prueba
            isLoadTestRunning = false;
        }
        else{ // Todo normal por aquí
            vMaxForImax = vIn;
            iMax = iIn;
        }
        
    }

    /***************************************************************************/
    /*                           ENCENDIDO Y APAGADO                           */
    /***************************************************************************/
    // Verifico los Limites para que el sistema permanezca encendido
    // Auto-apagado
    if(vIn <= vLimit && vRaw > VBATT_MIN && isPowerOn){// espero 250ms en el arranque
        // Apago 
        isPowerOn = false;
        // Apago la salida PWM y envio notificación en pantalla
        control_powerOff();
        digitalWrite(LED, HIGH);
    }

    // Detección de pulsación de botón  
    key = isButtonClicked(); // 0: no click, 1: short click, 2: long click, 3: double click
    if(key){
        if(!showMenu){ // Modo normal
            //  HUBO UNA PULSACIÓN LARGA
            if(key == LONG_CLICK){ // Reiniciamos los contadores

                notificationPriority = 1;
                notification_add("RESET COUNTERS", notificationPriority);

                clock_resetClock(timeDuration);
                
                control_resetCounters();

                tone(BUZZER_PIN, 1000,300);
            }

            // HUBO UN CLICK EN EL BOTÓN
            else if (key == SHORT_CLICK){
                // Una vez que se ejecuto el proceso de control ya no se 
                // mostraran algunas opciones que se ejecutan solo al arranque
                if(firstTime){
                    firstTime = false;
                }
                isPowerOn = not isPowerOn; // Cambia el estado anterior, de ENCENDIDO -> APAGADO y viceversa

                // ENCENDIDO
                if(isPowerOn){
                    forceRePrint = true;

                    notificationPriority = 2;
                    notification_add("   POWER ON   ", notificationPriority);
                    
                    tone(BUZZER_PIN, 4000, 50);
                    delay(20);
                    tone(BUZZER_PIN, 4500, 50);
                    delay(20);
                    tone(BUZZER_PIN, 5000, 50);
                    
                    Setpoint = ampereToAdc(ampereSetpoint);

                    coolerFan_powerOn();   
                    
                    #ifdef DEBUG
                    startTime = millis();
                    nextTime = startTime + WINDOW_CAPTURE;
                    #endif
                }
                // APAGADO
                else{
                    control_powerOff();
                    //myPID.SetMode(MANUAL);  // Apagamos el PID

                    coolerFan_powerOff();
                }
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

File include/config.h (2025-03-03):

/*
 *                      BLUE PILL PINOUT
 *
 *                  ,----------------------,
 *                  |o|PB12 | USB |   GND|o|          
 *   ENCODER_PIN_A  |o|PB13 '-----'   GND|o|  
 *   ENCODER_PIN_B  |o|PB14          3.3v|o|  
 *      BUTTON_PIN  |o|PB15          NRST|o|
 *                  |o|PA8           PB11|o|
 *                  |o|PA9           PB10|o|  
 *                  |o|PA10           PB1|o|  PWM_PIN [PWM_PIN1]
 *                  |o|PA11           PB0|o|  [PWM_PIN2]
 *                  |o|PA12           PA7|o|  
 *                  |o|PA15    /\     PA6|o|  
 *                  |o|PB3    /  \    PA5|o|  IBATT_SENSE_PIN
 * LCD_BKLIGHT_PIN  |o|PB4    \  /    PA4|o|  VBATT_SENSE_PIN
 *     LCD_RST_PIN  |o|PB5     \/     PA3|o|  FET_TEMP_SENSE_PIN
 *      LCD_CS_PIN  |o|PB6            PA2|o|
 *      LCD_DC_PIN  |o|PB7  =======   PA1|o|  BUZZER_PIN
 *     LCD_DIN_PIN  |o|PB8  =======   PA0|o|  COOLER_FAN_PIN
 *    LCD_SCLK_PIN  |o|PB9           PC15|o|
 *                  |o|5V            PC14|o|
 *                  |o|GND  . . . .  PC13|o|
 *                  |o|3.3V =======  VBAT|o|
 *                  '_'_____|_|_|_|______'_'
 *                          | | | |
 * 
 * 
 * 
 */



#ifndef _CONFIG_H
#define _CONFIG_H

// LED BUILTIN
#define LED         LED_BUILTIN // PC13

// LCD
#define LCD_SCLK_PIN        PB9
#define LCD_DIN_PIN         PB8
#define LCD_DC_PIN          PB7
#define LCD_CS_PIN          PB6
#define LCD_RST_PIN         PB5
#define LCD_BKLIGHT_PIN     PB4

// ENCODER and BUTTTON
#define ENCODER_PIN_A      PB13
#define ENCODER_PIN_B      PB14
#define BUTTON_PIN         PB15
#define ENCODER_VCC_PIN      -1 // Uso VCC de la placa
#define ENCODER_STEPS         4
#define ENCODER_CENTRAL_PIN_TO_VCC false // se usa pin central conectado a GND

// BUZZER
#define BUZZER_PIN          PA1 // Canal 2 de TIM2

// COOLER FAN
#define COOLER_FAN_PIN      PA0

//MOSFET TEMPERATURE
#define FET_TEMP_SENSE_PIN  PA3
#define FET_MAX_TEMP        100 //ºC máximos
#define FET_MIN_TEMP         30 //ºC mínimo para encender el cooler

// PWM
#define PWM1_PIN            PB1 // Canal 4 de TIM3
#define PWM2_PIN            PB0 // Canal 3 de TIM3

//#define FREQUENCY         10000 // 10KHz
#define PWM_INITIAL_DUTY      0 // 0%
#define PWM__RESOLUTION    4095 // Resolución de 12 bits

// VBATT IBATT
#define VBATT_SENSE_PIN     PA4
#define IBATT_SENSE_PIN     PA5

//PID
#define RESOLUTION PWM_RESOLUTION

// MODO DEPURACIÓN
/*  Para gráficar la respuesta con los parámetros PID seleccionados
 *  Utilizar la aplicación, en la PC, serial_port_plotter
 */
//#define DEBUG // Descomente esta linea para habilitar

#endif

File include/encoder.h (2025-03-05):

#ifndef _ENCODER_H
#define _ENCODER_H
#include <AiEsp32RotaryEncoder.h>
#include "config.h"
#include "constantes.h"

AiEsp32RotaryEncoder encoder = AiEsp32RotaryEncoder(ENCODER_PIN_A,
                                                    ENCODER_PIN_B,
                                                    BUTTON_PIN,
                                                    ENCODER_VCC_PIN,
                                                    ENCODER_STEPS,
                                                    ENCODER_CENTRAL_PIN_TO_VCC);

void readEncoderISR()
{
	encoder.readEncoder_ISR();
}

void encoder_init()
{
    pinMode(BUTTON_PIN, INPUT_PULLUP);
    encoder.begin();
    encoder.setup(readEncoderISR);
    bool circleValues = false;
    encoder.setBoundaries(0, 1000, circleValues); //minValue, maxValue, circleValues true|false (when max go to min and vice versa)
    //encoder.disableAcceleration(); //acceleration is now enabled by default - disable if you dont need it
    encoder.setAcceleration(150); //or set the value - larger number = more accelearation; 0 or 1 means disabled acceleration
    encoder.setEncoderValue(0);
    encoder.correctionOffset = 0;
}

void encoder_setBasicParameters(long minValue, long maxValue, bool circleValues=false , long newValue=0, long accel=150)
{
    encoder.setBoundaries(minValue, maxValue, circleValues);
    encoder.setEncoderValue(newValue);
    encoder.setAcceleration(accel);
}

enum ClickType {
    NO_CLICK,       // No hay pulsacion
    SHORT_CLICK,    // Pulsacion corta
    LONG_CLICK,     // Pulsacion larga
    DOUBLE_CLICK    // Doble pulsacion
};

bool wasButtonDown    = false; // se presiono el botón
bool checkDoubleClick = false; // si detecta una pulsación rápida es posible que venga una doble pulsación
bool longClickDetected;        // True: se forzó pulsación larga, ignorar click al soltar el botón
uint8_t _clickCounter=0; // 
int8_t lastMovementDirection = 0; // 1 right; -1 left

//paramaters for button
unsigned long shortPressAfterMiliseconds = 250; // Tiempo de espera para una pulsación corta
unsigned long longPressAfterMiliseconds = 1000; // ¿Cuánto tiempo se considera una pulsación larga?
unsigned long lastTimeButtonDown = millis();           // tiempo en el que duro la pulsación
unsigned long lastTimeButtonClick;
unsigned long maxTimeBetween2Events = 300;

bool isButtonDown()
{
    //return digitalReadFast(digitalPinToPinName(BUTTON_PIN))? false : true;
    return digitalRead(BUTTON_PIN)? false : true;
}

bool isButtonUp()
{
    return digitalReadFast(digitalPinToPinName(BUTTON_PIN))? true : false;
}

// Devuelve el tipo de pulsación detectado. Caso contrario, un NO_CLICK
uint8_t isButtonClicked()
{
    unsigned long timeDiff = millis() - lastTimeButtonDown;
    uint8_t key = NO_CLICK;
    bool currentButtonState = digitalReadFast(digitalPinToPinName(BUTTON_PIN));
    
    // Boton presionado, button down.
    if (!currentButtonState){
        // Lo hacemos por unica vez en cada ciclo click, button down a button up
        if(!wasButtonDown) {
            wasButtonDown = true;   //  No se ingresara aqui hasta el proximo inicio de click
            lastTimeButtonDown = millis();  // Iniciar el temporizador
            longClickDetected = false;
            //Serial.printf("button down\n");
        }
        // Si el boton permanece presionado, chequeo por pulzacion larga
        else{
            // Considerar como pulsación larga si se mantuvo presionado más de 'longPressAfterMiliseconds'
            if(timeDiff > longPressAfterMiliseconds){
                if(!longClickDetected){ // el boton sigue presionado?
                    key = LONG_CLICK;
                    longClickDetected = true;
                    //Serial.printf("Pulsacion Larga, Duracion: %d, Key:%d\n", timeDiff, key);
                } 
                // se ha detectado una pulsacion larga, por lo que no tiene sentido ahora preguntar por pulsacion corta
                return key;
            }
        }
    }
    // Boton liberado, se hizo click
    else{
        if(longClickDetected){ // Si hubo una pulsacion larga, reseteo valores para ignorar el click al soltar el boton
            longClickDetected = false;
            wasButtonDown = false;
        }
        else if (wasButtonDown){
            //Serial.printf("button up\n");
            _clickCounter++;
            //Serial.printf("Clicks = %d Time: %d ", _clickCounter, timeDiff);
            wasButtonDown = false;

            if (timeDiff > shortPressAfterMiliseconds){ // Se detecto pulsacion corta
                //Serial.printf("\n");
            } else { // Se detecto pulsacion corta y rapida. Posible intento de doble click?
                checkDoubleClick = true;
                //Serial.printf("Fast click\n");
            }
        }
    }
    // Pasado un tiempo maxTimeBetween2Events, veo si fue un click corto o un doble click rapido
    if(timeDiff>maxTimeBetween2Events && _clickCounter){
        if(_clickCounter==1){ // Solo se detecto una pulsacion, entonces es una pulsacion corta
            key = SHORT_CLICK;
            //Serial.printf("Pulsacion Corta\n");

        }
        else if(_clickCounter>1){ // Se detecto varias pulsaciones, entonces es un doble click (podria haber 3 o mas :P)
            if(checkDoubleClick){
                key = DOUBLE_CLICK;
                //Serial.printf("Doble Pulsacion\n");
            }
        }
        
        _clickCounter = 0;
        checkDoubleClick = false;
    }

    return key;
}


#endif

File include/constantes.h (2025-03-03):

#ifndef _CONST_H
#define _CONST_H

// Tiempo
#define TIME_1SEG      1000 // Intervalo de 1 segundo

// Medición de Tensión
#define R1            100.0
#define R2             20.0
#define GAIN_V (R2/(R1+R2))
#define ADCRAW_1V      50.4
#define V3_3            3.3
// Tensión
#define VBATT_MIN         2 // Vbatt min. para indicar si hay fuente conectada

// Medición de Corriente
#define R3             10.0
#define R4             20.0
#define GAIN_I (R4/(R3+R4))
#define SENSIBILITY   0.185 // Modelo ACS712 5A
#define IADCOFFSET    513.4 // ADC medido en vació
#define ADCRAW_1A     555.1 // ADC medido con una corriente de 1A
#define ADC_1A_DIFF   41.65 // Diferencia, en valores de ADC, desde 0 a 1A
                         
#define MU            0.001 // Tasa de aprendizaje, Filtro Adaptativo con 0<x<1

// MOSFET
#define ADC_VGS_THRESHOLE  2400 // Tensión mínima de conducción para este IRFZ44

// PID
//      https://pidtuner.com/
//          Proportional Gain= 35
//          Integral Time= 1
//          Derivative Time= 0.1
//          Integral Gain= 35
//          Derivative Gain= 3.5
// Constantes en modo Conservativo
#define KP_CNSTIVE     15.0
#define KI_CNSTIVE     15.0
#define KD_CNSTIVE      1.5
// Constantes en modo Agresivo
#define KP_AGG         35.0
#define KI_AGG         35.0
#define KD_AGG          3.5

#define PID_WINDOW_SIZE  10 // 10 mili segundos

#endif

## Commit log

2024-09-04 Sensado y calculo de V e I de carga
2024-09-04 Primer testeo de la Carga, funcional
2024-09-05 Prueba de implementar PID
2024-09-06 Primera implementacion funcional del PID
2024-09-09 Mejoras en el algoritmo de calculo para mediciones de V e I
2024-09-09 Implementacion del calculo para Wh y Ah
2024-09-09 Imprimir en el LCD unicamente lo que se actualizo
2024-09-09 Se agrega proyecto en KiCAD del Hardware utilizado
    [Carga Electronica.kicad_pcb, Carga Electronica.kicad_sch]
2024-09-09 fix al crear enlaces a archivos
    [Carga Electronica.kicad_pcb, Carga Electronica.kicad_sch]
2024-09-10 Implementacion de doble salida PWM
2024-09-10 Muestra el Setpoint cuando no esta funcionando
2024-09-10 Implementacion funcional de doble mosfet
2024-09-10 reimplementacion de floatTostr()
2024-09-11 Teniendo en cuenta Vgs_threshold. Valor particular de cada MOSFET
2024-09-11 Chequeo continuo de la Tension de entrada de Bateria/Fuente
2024-09-11 se agrega reseteo de contadores mediante pulsacion larga
    [main.cpp]
2024-09-12 testeo de tension de entrada y prioridad en la notificaciones
2024-09-13 modificacion del sistema de notificaciones
2024-09-13 reordeno la impresion de temperatura
2024-09-13 notificaciones por exceso de temperatura
2024-09-15 mala edicion de readme.md
2024-09-20 correccion de readme.md
2024-10-02 resolviendo problemas del algoritmo de control PID
    [config.h, constantes.h, encoder.h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]
2024-10-02 acomodando el algoritmo del boton
2024-10-02 Se cambio el divisor resistivo por R de precision
    [Carga Electronica.kicad_sch]
2024-10-03 fix sobreimpulso al volver a conectar la bateria con la carga activada
    [config.h, constantes.h, main.cpp]
2024-10-07 fix notificacion cuando se desconecta bateria en funcionamiento y se apaga la carga
    [config.h, main.cpp]
2024-10-09 se agrega nuevo entorno para emular mediante PICSIMLAB
2024-10-09 fix mensaje de "no battery" cuando se decsconectaba la bateria y se variaba el Setpoint
    [main.cpp]
2024-10-09 deteccion de pulsacion, se actua solo si se detecta un valor True
2024-10-10 solo estando encendida se muestra el reloj con colores invertidos
2024-10-10 organizando codigo para mejor legibilidad
2024-10-13 se agrega deteccion de doble click rapido del boton para futuros usos
2024-10-13 se agragan archivos de simulacion para PICSIMLAB
2024-10-13 readme.md dentro de `simulacion`
2024-10-14 retoques en 'encoder.h'
2024-10-14 optimizado `encoder.h`
2024-10-15 se agrega soporte para menus, se inicia con un doble click
2024-10-16 reorganizando funciones de encoder.h y display.h dentro de menu.h
2024-10-16 mejoras en el resaltado de un Item seleccionado en el menu
2024-10-17 se agrega acciones para los parametros de calibracion de I
2024-10-18 se intento implementar MODOS, por ahora con problemas en la impresion de mediciones
    [main.cpp]
2024-10-22 reorganizando el codigo
2024-10-23 se modifica la forma que se muestra al cargar el Periodo de Tiempo
2024-10-23 ahora se muestra el tiempo en decremento en MODO TIEMPO
2024-10-24 se agrega seleccion de modo en funcion `Tiempo`
2024-10-24 se agrega video de demostracion en readme.md
    usando PICSIMLAB para emular la placa de control
2024-10-24 fix al reiniciar los contadores, totalTime debe tomar un valor dependiendo del modo seleccionado
    [main.cpp]
2024-10-24 se establece identacion de 4 espacion en los archivos que tenian 2 espacios
2024-10-24 cambio delay por click para cerrar el mensaje
2024-10-24 se agrega mensaje "click -> salir" cuando se muestra mensaje de información
2024-10-25 se agrega modo Resistencia Constante
2024-10-25 fix modo R constante, ahora en funcionamiento
    [main.cpp]
2024-10-25 fix variables de tiempo no tomaban los valores correctos al cambiar de modo
    [main.cpp]
2024-10-25 detener las salidas pwm si entro al submenu `Tiempo`
2024-10-25 renicio de contadores cuando se cambia de modo de operacion
2024-10-25 todos los modos de trabajo funcionando
2024-10-26 se cambia la presentacion del menu
2024-10-29 se agrega modo ´Prueba de Carga`
2025-01-04 Cambio en la escala para I < 1A
2025-02-12 Interrupcio de notificacion de No Battery dentro del Menu
2025-02-12 fix notificaciones al estar Menu activo
    [main.cpp]
2025-02-14 se implemento el guardado de parametros de calibracion en la EEPROM
2025-02-19 evitar arranque involuntario en modo Calibracion en el arranque
2025-02-19 se agrega configuracion inicial de Vmin de corte y Corriente de la Carga
2025-02-20 modificación en la selección de Vmin
2025-02-20 al arrancar de forma directa, solo un click corto, no se seteaba correctamente la corriente de carga
    [main.cpp]
2025-02-24 al iniciar, para comenzar a configurar un parámetro se deberá girar hacia la izquierda sobre el deseado y luego un click para guardar
2025-02-25 se mejora la configuración y arranque inicial. Solo se modificara el parámetro si se hace un giro izquierdo rápido
2025-02-26 se modifica la forma de selección del Modo de Control, en modo Timer
2025-02-26 se actualizo el video demo
2025-03-03 fix, no se podía cambiar de menu Item cuando se esta en modo _Prueba de Carga_
    [encoder.h, main.cpp]
2025-03-03 sin cambios en el código, solo ortografía
2025-03-05 se agrego la opción Reset al Menú
    [encoder.h]
2025-03-11 mejoras en la interfaz humana
2025-03-12 fix, no se mostraba el resumen de valores medidos cuando se detenía el proceso
    [main.cpp]
2025-03-13 fix, en modo Rcte y Pcte, arrancaba con valores por defecto incorrectos
    [main.cpp]
2025-03-14 fix, tras salir del menu no se actualizaba correctamente la configuración del encoder y la impresión del tiempo
    [main.cpp]
2025-03-17 refresco de pantalla cada 20mesg
2025-03-17 fix, si cambiaba de modo de trabajo, estando el anterior en funcionamiento, el proceso no se reiniciaba/apagaba
    [main.cpp]
